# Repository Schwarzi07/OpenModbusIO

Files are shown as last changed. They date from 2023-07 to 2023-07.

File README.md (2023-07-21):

# OpenModbusIO
Hardware and software for Mobus based remote IO

# Goal
The goal of this project is to create open source IO for Modbus TCP or Modbus RTU. This repository will hold the source code and the PCB design files for this project. 

# Software
Currnetly the software is written in C++ on the Arduino platform via Visual Studio Code and PlatformIO. My plans are to switch to an RTOS when the hardware expands.

# Hardware
The hardware is curently based on Arduino and is using the Arduino Ethernet shield with the Wiznet w5500 Ethernet controller.
I design the PCBs in KiCad and will limit myself to two layers to keep costs low and enable DIY PCB fabrication using CNC milling or other methods.

# current status
Currnetly I have basic software and a shield for an Arduino UNO.

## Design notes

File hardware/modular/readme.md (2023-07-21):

will start developement of modular devices if the software for fixed devices is done

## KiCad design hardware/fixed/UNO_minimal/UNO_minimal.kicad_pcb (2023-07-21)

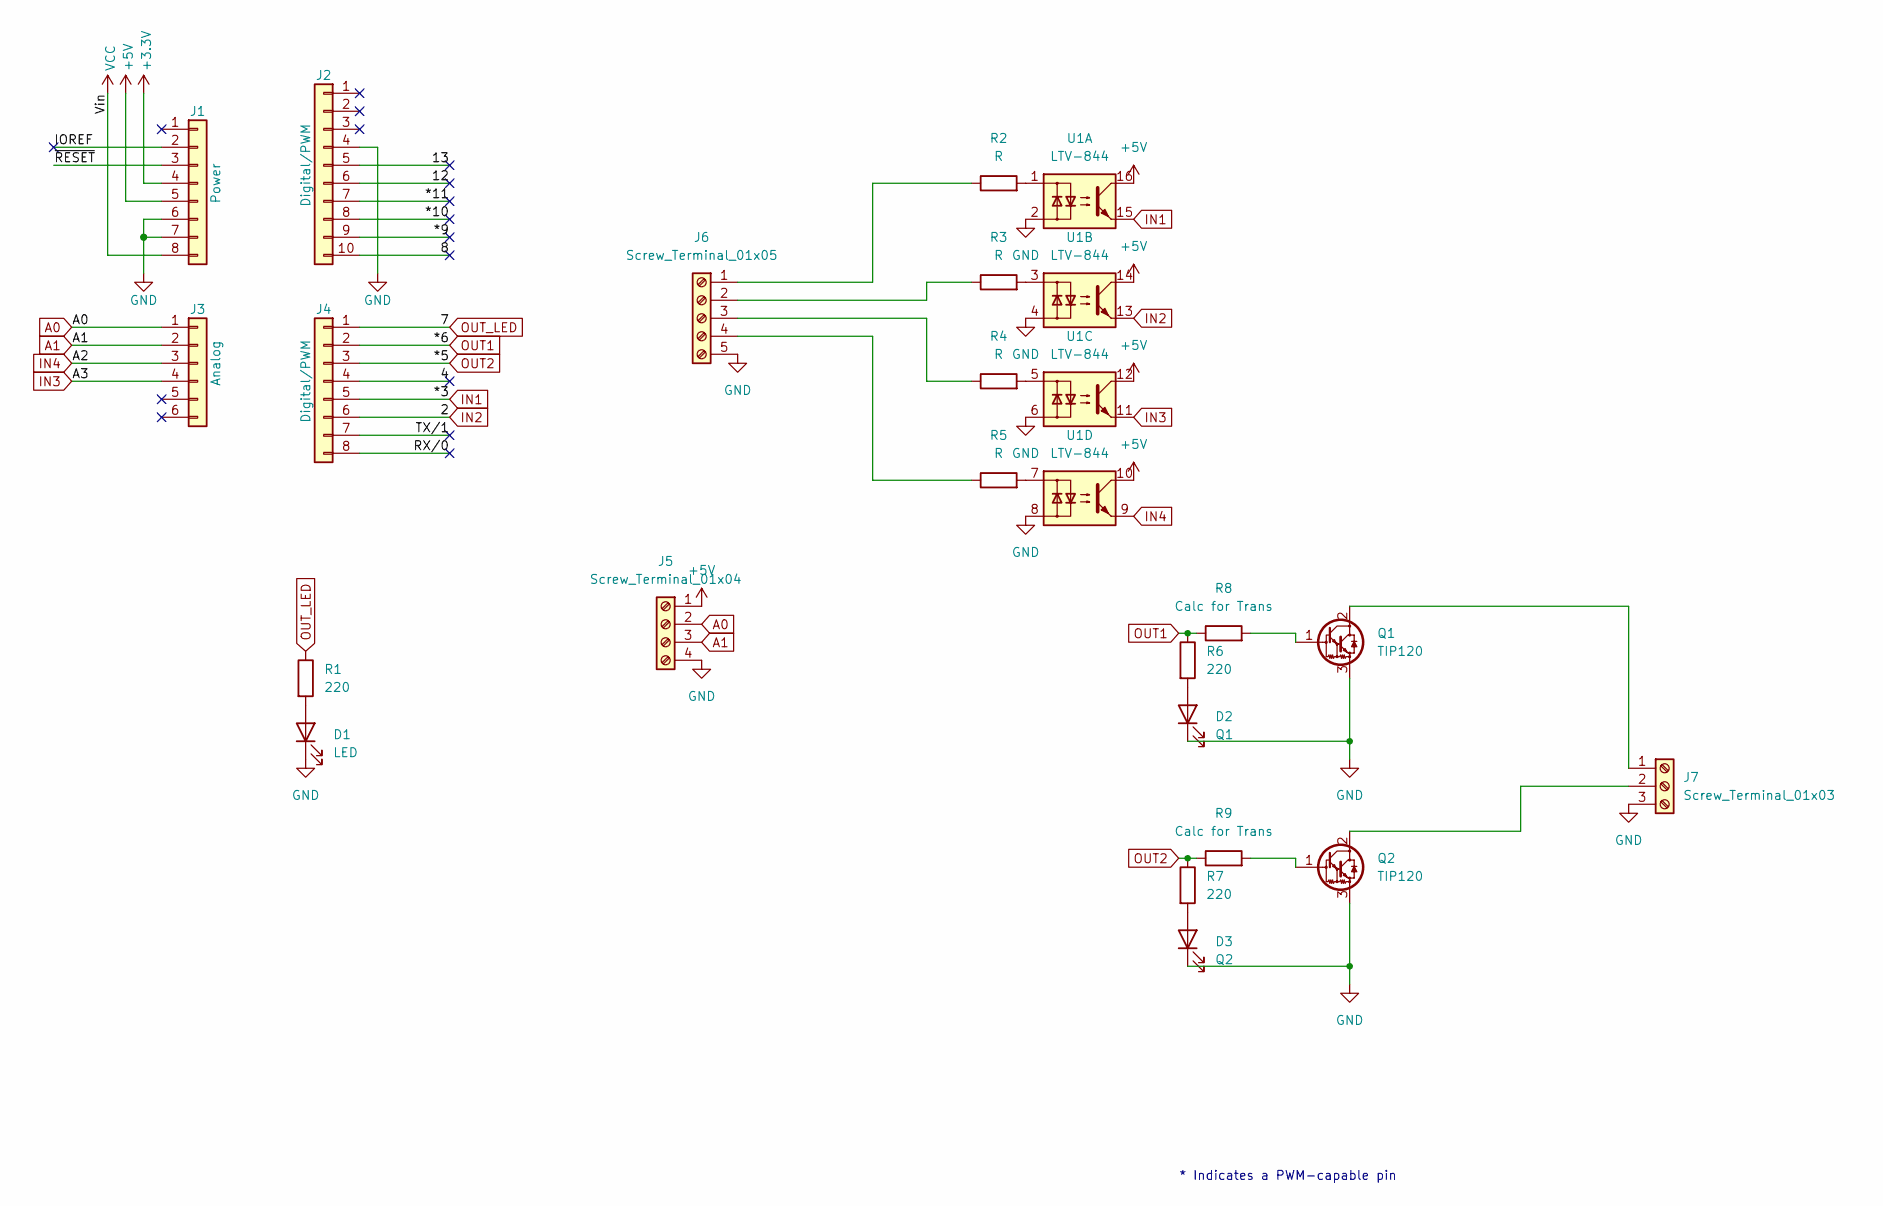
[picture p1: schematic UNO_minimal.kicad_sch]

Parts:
D1: LED; LED_D3.0mm
D2: Q1; LED_D3.0mm
D3: Q2; LED_D3.0mm
J1: Power; PinSocket_1x08_P2.54mm_Vertical
J2: Digital/PWM; PinSocket_1x10_P2.54mm_Vertical
J3: Analog; PinSocket_1x06_P2.54mm_Vertical
J4: Digital/PWM; PinSocket_1x08_P2.54mm_Vertical
J5: Screw_Terminal_01x04; TerminalBlock_WAGO_236-104_1x04_P5.00mm_45Degree
J6: Screw_Terminal_01x05; TerminalBlock_WAGO_236-105_1x05_P5.00mm_45Degree
J7: Screw_Terminal_01x03; TerminalBlock_WAGO_236-103_1x03_P5.00mm_45Degree
Q1, Q2: TIP120; TO-220-3_Vertical
R1, R6, R7: 220; R_Axial_DIN0204_L3.6mm_D1.6mm_P5.08mm_Vertical
R2, R3, R4, R5: R; R_Axial_DIN0204_L3.6mm_D1.6mm_P5.08mm_Vertical
R8, R9: Calc for Trans; R_Axial_DIN0204_L3.6mm_D1.6mm_P5.08mm_Vertical
U1: LTV-844; DIP-16_W7.62mm

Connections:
+3V3: J1.4
+5V: J1.5, J5.1, U1.10, U1.12, U1.14, U1.16
/4: J4.4
/8: J2.10
/12: J2.6
/13: J2.5
/*9: J2.9
/*10: J2.8
/*11: J2.7
/IOREF: J1.2
/RX/0: J4.8
/TX/1: J4.7
/~RESET: J1.3
A0: J3.1, J5.2
A1: J3.2, J5.3
GND: D1.1 (K), D2.1 (K), D3.1 (K), J1.6, J1.7, J2.4, J5.4, J6.5, J7.3, Q1.3 (E), Q2.3 (E), U1.2, U1.4, U1.6, U1.8
IN1: J4.5, U1.15
IN2: J4.6, U1.13
IN3: J3.4, U1.11
IN4: J3.3, U1.9
unnamed: D1.2 (A), R1.2
unnamed: D2.2 (A), R6.2
unnamed: D3.2 (A), R7.2
unnamed: J6.1, R2.1
unnamed: J6.2, R3.1
unnamed: J6.3, R4.1
unnamed: J6.4, R5.1
unnamed: J7.1, Q1.2 (C)
unnamed: J7.2, Q2.2 (C)
unnamed: Q1.1 (B), R8.2
unnamed: Q2.1 (B), R9.2
unnamed: R2.2, U1.1
unnamed: R3.2, U1.3
unnamed: R4.2, U1.5
unnamed: R5.2, U1.7
OUT1: J4.2, R6.1, R8.1
OUT2: J4.3, R7.1, R9.1
OUT_LED: J4.1, R1.1
VCC: J1.8

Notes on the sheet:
* Indicates a PWM-capable pin

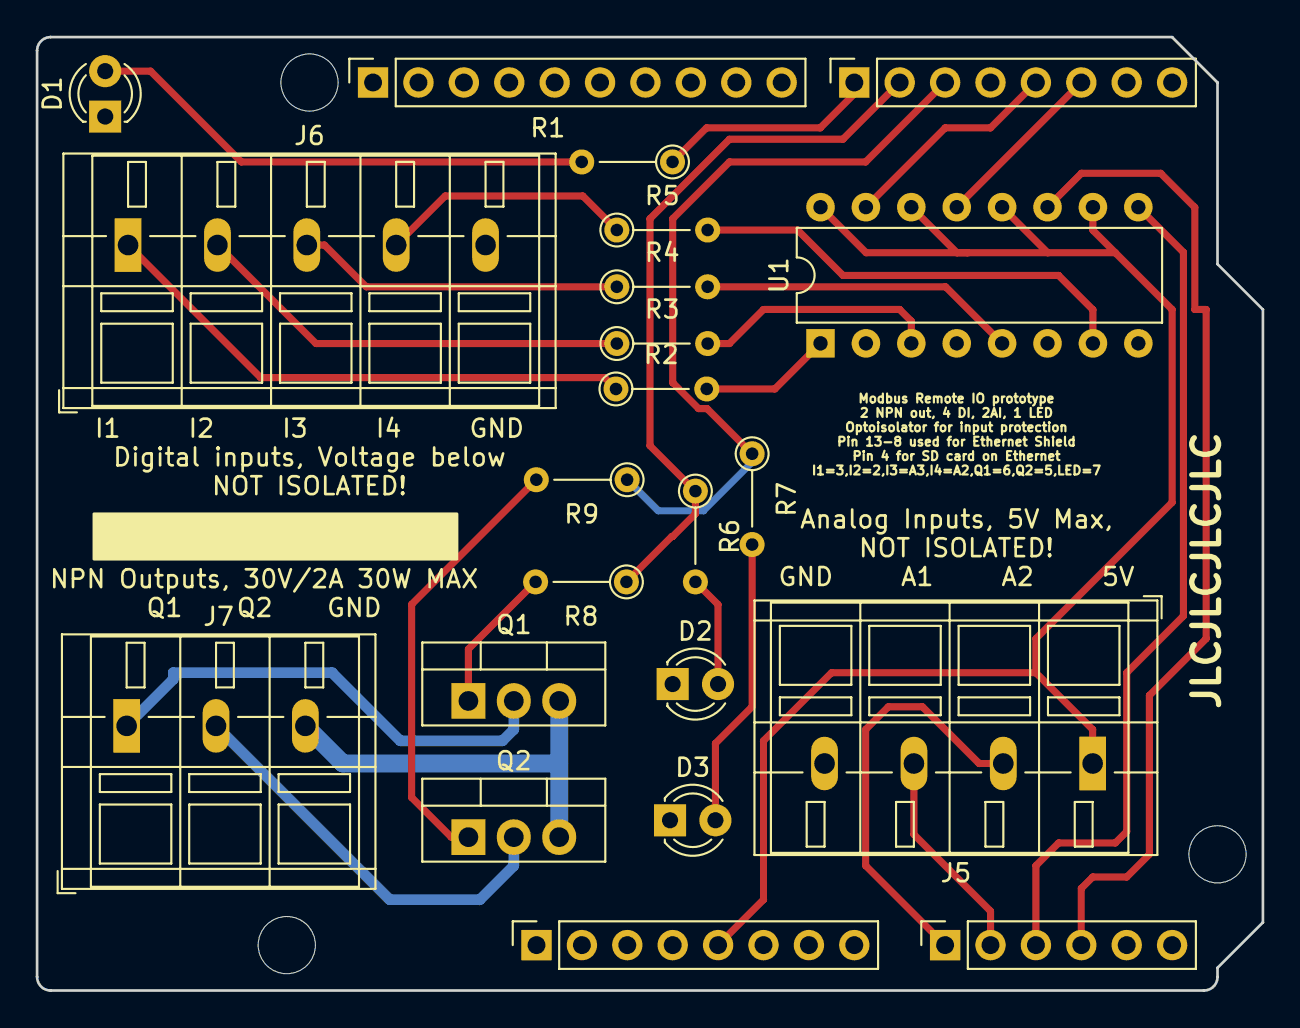
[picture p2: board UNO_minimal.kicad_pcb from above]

Board: 2 copper layers, 68.6 x 53.3 mm, 25 parts (0 on the bottom side), 26 nets.

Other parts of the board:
MH1, MH2, MH4: MountingHole_3.2mm

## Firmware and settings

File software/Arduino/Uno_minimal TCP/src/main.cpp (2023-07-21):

#include <Arduino.h>
#include <SPI.h>
#include <Ethernet.h>       // Ethernet library v2 is required
#include<EthernetUdp.h>
#include <ModbusEthernet.h>

//Ethernet configuration
byte mac[] = {
  0xa8, 0x61, 0x0a, 0xae, 0xe4, 0x39
};
IPAddress ip(192, 168, 2, 101);

//declare pins
const int i1 = 5;
const int i2 = 6;
const int i3 = A2;
const int i4 = A3;

const int a1 = A0;
const int a2 = A1;

const int q1 = 6;
const int q2 = 7;
const int led = 5;

const int ethernet_ss = 10;


// ModBus Registers offsets
const int i_1 = 100;
const int i_2 = 101;
const int i_3 = 102;
const int i_4 = 103;

const int a_1 = 200;
const int a_2 = 201;

const int q_1 = 300;
const int q_2 = 301;
const int q_led = 302;

//ModBus Object
ModbusEthernet mb;



void setup() {
  Serial.begin(9600);
  Serial.println("Setting Pins");
  //set pins
  pinMode(i1, INPUT);
  pinMode(i2, INPUT);
  pinMode(i3, INPUT);
  pinMode(i4, INPUT);
  pinMode(q1, OUTPUT);
  pinMode(q2, OUTPUT);
  pinMode(led, OUTPUT);
  //init Ethernet
  Serial.println("Intitializing Ethernet");
  Ethernet.init(ethernet_ss);        
  Ethernet.begin(mac, ip);  
  delay(1000);         
  Serial.print(Ethernet.localIP());
  //init modbus
  Serial.println("Initializing Modbus");
  mb.server();
  //add registers
  Serial.println("Adding registers");
  mb.addIsts(i_1);
  mb.addIsts(i_2);
  mb.addIsts(i_3);
  mb.addIsts(i_4);

  mb.addIreg(a_1);
  mb.addIreg(a_2);

  mb.addCoil(q_1);
  mb.addCoil(q_2);
  mb.addCoil(q_led);
  Serial.println("Done!");
}

void loop() {
  mb.task();
  digitalWrite(q1, mb.Coil(q_1));
  digitalWrite(q2, mb.Coil(q_2));
  digitalWrite(led, mb.Coil(q_led));

  mb.Ists(i_1, digitalRead(i1));
  mb.Ists(i_2, digitalRead(i2));
  mb.Ists(i_3, digitalRead(i3));
  mb.Ists(i_4, digitalRead(i4));

  mb.Ireg(a_1, analogRead(a1));
  mb.Ireg(a_2, analogRead(a2));
}

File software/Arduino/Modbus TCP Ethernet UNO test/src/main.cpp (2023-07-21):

#include <Arduino.h>
#include <SPI.h>
#include <Ethernet.h>       // Ethernet library v2 is required
#include<EthernetUdp.h>
#include <ModbusEthernet.h>


//Ethernet configuration
byte mac[] = {
  0xa8, 0x61, 0x0a, 0xae, 0xe4, 0x39
};
IPAddress ip(192, 168, 2, 101); // The IP address will be dependent on your local network:

//declare pins
const int led = 9;
const int but = 8;
const int temp = A0;


// ModBus Registers offsets
// Holding registers
const int TEST_HREG = 100;
//coils
const int TEST_COIL = 200;
// discrete inputs
const int TEST_BUTT = 300;
//analog input registers
const int TEST_SENS = 400;
const int TEMP_INT  = 401;


//ModBus Object
ModbusEthernet mb;

//var
long ts;
long intervall; //intervall for scanning analog inputs




void setup() {
  // put your setup code here, to run once:
  pinMode(but, INPUT);
  pinMode(led, OUTPUT);
  //digitalWrite(led,HIGH);
/*digitalWrite(led, HIGH);
  delay(500);
  digitalWrite(led,LOW);
  delay(500);
  digitalWrite(led, HIGH);
  delay(500);
  digitalWrite(led,LOW);
  delay(500);
  digitalWrite(led, HIGH);
  delay(500);
  digitalWrite(led,LOW);*/
  ts = millis();
  intervall = 2000;

  Serial.begin(9600);     // Open serial communications and wait for port to open
  #if defined(AVR_LEONARDO)
  while (!Serial) {}        // wait for serial port to connect. Needed for Leonardo only
  #endif
  Ethernet.init(10);        // SS pin
  Ethernet.begin(mac, ip);  // start the Ethernet connection
  delay(1000);         
  Serial.print(Ethernet.localIP());     // give the Ethernet shield a second to initialize
  
  mb.server();              // Act as Modbus TCP server (slave)
  mb.addHreg(TEST_HREG, 0xABCD);  
  mb.addCoil(TEST_COIL);
  mb.addIsts(TEST_BUTT);
  mb.addIreg(TEST_SENS);
  mb.addIreg(TEMP_INT);
  
  
}

void loop() {
  // put your main code here, to run repeatedly:
  //Modbus Task(does the black magic)
  mb.task();
  delay(50); //remove or lower if other things in loop, speeds up respones via ModBus
  digitalWrite(led, mb.Coil(TEST_COIL));
  mb.Ists(TEST_BUTT, digitalRead(but));

  if (millis() > ts + intervall){
    mb.Ireg(TEST_SENS, random(50));
    mb.Ireg(TEMP_INT, map(analogRead(temp), 0, 307, 0, 150)); //internal temp sens
  }
}

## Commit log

2023-07-21 added files from local storage to github
    [UNO_minimal-B_Cu.gbr, UNO_minimal-B_Silkscreen.gbr, UNO_minimal-Edge_Cuts.gbr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]
2023-07-21 Revert "added files from local storage to github"
    This reverts commit 45506ca0ecf017dd25e77392b1a3004c5c51514a.
    [UNO_minimal-B_Cu.gbr, UNO_minimal-B_Silkscreen.gbr, UNO_minimal-Edge_Cuts.gbr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]
2023-07-21 add files from local storage
    [UNO_minimal-B_Cu.gbr, UNO_minimal-B_Silkscreen.gbr, UNO_minimal-Edge_Cuts.gbr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]
2023-07-21 new software for UNO_minimal board
